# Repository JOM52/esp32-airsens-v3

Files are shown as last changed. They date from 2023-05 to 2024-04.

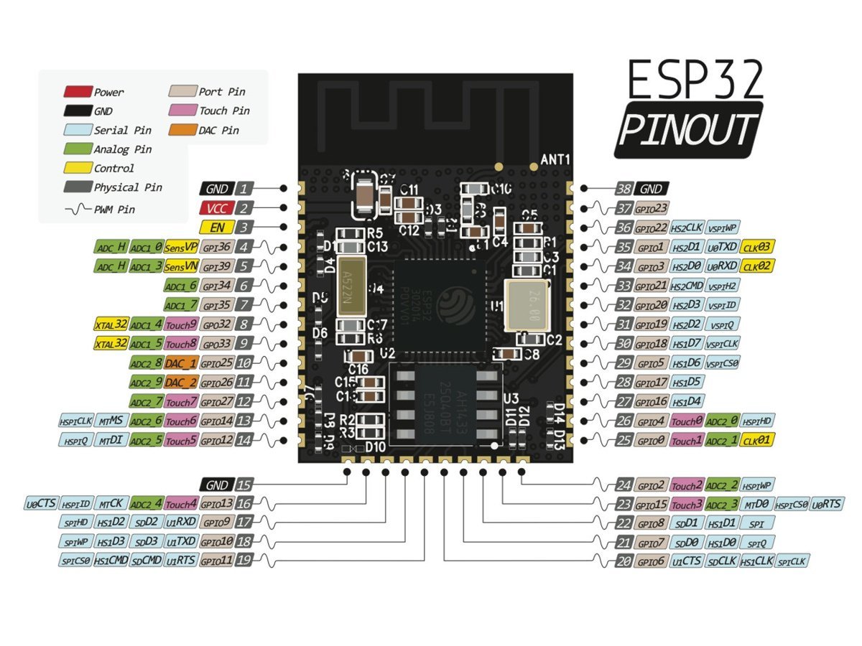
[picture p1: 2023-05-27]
doc/esp32-wroom-32_pinout.jpg

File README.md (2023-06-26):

# Projet : esp32-airsens 

Version 3

Dénomination des éléments:

- **Capteur (Sensor)**: composant qui permet la mesures d'une ou plusieurs grandeurs physiques;
- **Module de capteur ( Sensor module)**: microcontrôleur qui contrôle un ou plusieurs capteurs et se charge de transmettre les données vers une centrale;
- **Centrale (Host)**: microcontrôleur qui reçoit les données d'un ou plusieurs terminaux de mesure et qui les transmets vers un serveur domotique de type MQTT

**esp32-airsens** est un projet de domotique qui vise à créer des petits appareils intelligents et connectés pour contrôler l'environnement. Ils utilisent le processeur ESP32 et le langage Micropython. Ils peuvent détecter différents paramètres comme la température, l'humidité, la pression de l'air et le niveau de batterie. Ils transmettent ensuite ces données à une station centrale via un réseau sans fil. La station centrale est un système Liligo-TTGO qui reçoit les données des appareils, les publie sur un broker MQTT et les montre sur un écran. L'écran permet de visualiser les informations pertinentes pour chaque Module de capteur.

La version 3 du projet est basée sur la version 2 et introduit les éléments suivants:

- Association semi-automatique du Module de capteur et de la centrale.
- Lors de l'association du Module de capteur et de la centrale le terminal informe automatiquement la centrale du ou des capteurs connectés, des grandeurs mesurées ainsi que de l'ordre dans lequel ces informations seront transmises à la centrale par chaque terminal. 
- Identification du terminal par son adresse MAC
- Identification d'une mesure par l'adresse MAC du terminale de mesure ainsi que par le type de capteur utilisé.

## Schéma de principe
https://github.com/JOM52/esp32-airsens-v3/blob/main/schema/airsens_v3_0%20schema%20de%20principe.odg

## Module de capteur:

La version V1.0 proto du hardware fonctionne bien. Dans cette nouvelle version, le hardware est complétée avec un bouton et une led pour démarrer et contrôler le processus d'association du capteur avec la centrale. 

Pour réduire la consommation d'énergie, cette version hard ne contient que l'essentiel pour faire fonctionner le terminal. La configuration se fait, depuis le PC,  par une interface FTDI (USB to UART) qui se branche au besoin et, les batteries se rechargent à part.

https://github.com/JOM52/esp32-airsens-v3/blob/main/schema/airsens_v3_0.kicad_sch

### Hardware

Le hardware ESP32 est un microcontrôleur qui intègre des fonctionnalités de Wi-Fi et de Bluetooth, ainsi que des modules de gestion de l'alimentation, des filtres et des amplificateurs. Il peut se connecter à différents types de capteurs I2C, et transmets ces données vers la centrale par  le protocole de communication série synchrone ESP-now. 

##### firmware esp32/espnow

la version du firmware est trouvée sur le site: 
**[GitHub - glenn20/micropython-espnow-images: A collection of pre-compiled micropython images (including espnow support) for the esp32 and esp8266.](https://github.com/glenn20/micropython-espnow-images)** 
dans le répertoire:
**20220709_espnow-g20-v1.19.1-espnow-6-g44f65965b**
et le fichier est:
**firmware-esp32-GENERIC.bin**

Ce firmware convient pour les processeurs ESP32-WROOM-32 et Liligo TTGO t-display

**Attention:** la version v1.20.0 est sortie mais pose des problèmes au niveau de la communication espnow. De nombreux messages sont perdus. Donc on reste sur la version v1.19.1

##### Evolution airsens V3s:

- Ajout d'une cellule photovoltaïque pour la recharge en continu de la batterie du capteur.

### Software

Ce projet implémente les drivers pour les capteurs de type BME280, BME680 et HDC1080. Ces capteurs permettent de mesurer différentes grandeurs liées au climat ou à l'environnement. Depuis la version 2 du projet, on peut choisir le type et le nombre de capteurs à utiliser dans le fichier de configuration. Cette possibilité doit être utilisée à bon escient en tenant compte de l'impact sur la consommation dons sur l'autonomie de la batterie. Avec une batterie Li-Ion de 2Ah (type 18650), on peut, avec un seul capteur,  en prenant une mesure toutes les 5 minutes avoir un autonomie d'environ un an.

#### Fichier de configuration du capteur

Le fichier de configuration permet de personnaliser le fonctionnement d'un capteur sans avoir à modifier le code source. Il contient du code Micropython qui assigne des valeurs à des variables globales. Ces variables sont ensuite utilisées par le programme principal pour paramétrer les différents éléments du système. Le fichier de configuration n'a pas besoin d'une structure particulière, mais il peut être organisé en sections pour faciliter la lecture et la compréhension.

Le code ci-après permet de configurer un capteur connecté à un ESP32. Le capteur peut être de type hdc1080, bme280 ou bme680 et mesure la température, l'humidité, la pression, le gaz et l'altitude selon le cas. 

Le Module de capteur est alimenté par une batterie Li-Ion de 3.7V (3.2V - 4.2V) - type 6850. Pour économiser l'énergie consommée, le terminal est placé en ***deepsleep*** entre chaque mesure. Le temps de sommeil est défini dans le fichier de configuration. Lors d'un éveil, le processeur lit le fichier de configuration, initialise les constantes, charge les librairies nécessaire, initialise le capteur, fait la mesure, mesure l'état de la batterie, transmets les valeurs à la centrale puis se met en ***deepsleep***

La tension de la batterie est mesurée par un pont diviseur de tension. 

Le code utilise les constantes définies au début du fichier pour paramétrer les différents éléments du système. Par exemple, SENSOR_LOCATION indique le nom du capteur, T_DEEPSLEEP_MS indique la durée du mode deepsleep en millisecondes, SENSORS indique les types de capteurs disponibles et leurs mesures associées, ON_BATTERY indique si le capteur est alimenté par une batterie ou non, etc. 

L'association capteur-centrale .............................. à compléter ................................................

Le code ci-dessous montre un exemple de fichier de configuration pour ce système:

```
# acquisitions
SENSOR_LOCATION = 'domo_2' 
T_DEEPSLEEP_MS = 300000
# sensor
SENSORS = {
    'hdc1080':['temp', 'hum'],
    'bme280':['temp', 'hum', 'pres'],
    'bme680':['temp', 'hum', 'pres', 'gas', 'alt'],
  }
# power supply
TO_PRINT = True
ON_BATTERY = True
UBAT_100 = 4.2
UBAT_0 = 3.2
# I2C hardware config
BME_SDA_PIN = 21
BME_SCL_PIN = 22
# analog voltage measurement
R1 = 977000 # first divider bridge resistor
R2 = 312000 # second divider bridge resistor
DIV = R2 / (R1 + R2)  
ADC1_PIN = 35 # Measure of analog voltage (ex: battery voltage following)
#averaging of measurements
AVERAGING = 1
AVERAGING_BAT = 1
AVERAGING_BME = 1

# ESP-now
PROXY_MAC_ADRESS = '3C:61:05:0D:67:CC'
WIFI_CHANNEL = 1
```

### Messages

Les valeurs mesurées pour chaque grandeur sont regroupées et transmises au broker MQTT dans un seul message. Le format de principe du message est le suivant:

`msg = (topic, location, grandeur 1, grandeur 2, .... , grandeur n, bat, rssi)`

Les grandeurs mesurées sont dépendantes des possibilités du capteur par exemple:

- HDC1080 : température, humidité
- BME280  : température, humidité, pression
- BME680  : température, humidité, pression, qualité de l'air

Les valeurs transmises à MQTT sont fonction de la configuration définie dans le fichier _conf du capteur.

## Centrale

### Software

La centrale est le cœur du système de domotique. Elle a plusieurs fonctions :

- Elle reçoit et traite les messages valides envoyés par les capteurs sans fil.
- Elle adapte les messages au format de l'application de domotique choisie (domoticz, jeedom, ...).
- Elle transmet les valeurs de mesure à MQTT, un protocole de communication qui permet de diffuser les informations aux abonnés.
- Elle affiche différentes informations sur un écran couleur, comme les mesures et l'état des batteries des capteurs.

Les messages reçus ne sont pas confirmés au capteur. Cela signifie que si la centrale n'est pas disponible au moment où le capteur envoie un nouveau message, celui-ci est perdu. En principe cela ne pose pas de problème pour les mesures de grandeurs physiques qui varient peu dans le temps.

La centrale accepte tous les messages qui ont une structure correcte et qui proviennent d'un capteur dont elle connaît l'adresse MAC. Si le capteur est déjà enregistré dans le fichier de configuration et dans la mémoire programme, les nouvelles valeurs remplacent les anciennes. Sinon, le capteur est automatiquement reconnu et ajouté au fichier de configuration et à la mémoire programme.

La centrale dispose de deux boutons sur la version matérielle des Lilygo-ttgo qui permettent de sélectionner les différents affichages programmés. le choix se fait lorsque aucun bouton n'est pressé pendant 1 seconde.

Pour transmettre les mesures à MQTT, la centrale se connecte au réseau WIFI. Les valeurs de mesure sont formatées selon les besoins de l'application de domotique choisie puis envoyées au broker MQTT qui les publie aux abonnés.

### Fichier de configuration de la centrale

Le fichier de configuration est un fichier standard Micropython. 

```
#!/usr/bin/env python3
# -*- coding: utf-8 -*-
"""
file: airsens_central_conf.py 

author: jom52
email: jom52.dev@gmail.com
github: https://github.com/JOM52/esp32-airsens-class

v0.4.0 : 05.02.2023 --> first prototype
v0.4.1 : 05.03.2023 --> small changes Venezia
"""
from ubinascii import hexlify
from machine import unique_id
#SYSTEM
WAIT_TIME_ON_RESET = 10 # seconds to wait before the machine reset in case of error
# MQTT
BROKER_IP = '192.168.1.108'
TOPIC = 'airsens_v2'
BROKER_CLIENT_ID = hexlify(unique_id())

# TTGO
BUTTON_MODE_PIN = 35
BUTTON_PAGE_PIN = 0
DEFAULT_MODE = 0 # Mode auto
DEFAULT_ROW_ON_SCREEN = 5 # given by the display hardware and the font size
CHOICE_TIMER_MS = 1000 # milli seconds
BUTTON_DEBOUNCE_TIMER_MS = 10 # milli seconds
REFRESH_SCREEN_TIMER_MS = 20000 # mode auto: display next location each ... milli seconds

# WIFI
WIFI_WAN = 'jmb-airsens'
WIFI_PW = 'lu-mba01'

# BATTERY
BAT_MAX = 4.2 # 100%
BAT_MIN = 3.2 # 0%
BAT_OK = 3.4 # si ubat plus grand -> ok
BAT_LOW = 3.3 # si ubat plus petit -> alarm
BAT_PENTE = (100-0)/(BAT_MAX-BAT_MIN)
BAT_OFFSET = 100 - BAT_PENTE * BAT_MAX
# print('Charge bat % = ' + str(BAT_PENTE) + ' * Ubat' + ' + ' + str(BAT_OFFSET))

```

#### Code de la centrale évolution

*Dans une prochaine version il est prévu de modifier le programme pour:*

- *de crypter les message pour empêcher que les messages soient lus par des entités non autorisées.*

### Hardware

La centrale utilise un circuit Lilygo-ttgo qui comprend le processeur, une interface USB, un affichage de 135x240 pixels et deux boutons. Dans la version actuelle, ce circuit est utilisé tel quel. Les boutons sont utilisés comme suit:

- bouton 1 --> next **Mode**

- bouton 2 --> next **Page**

  le choix se fait lorsque aucun bouton n'est pressé pendant 1 seconde

### Connection réseau attribution des canaux

Il faut désactiver l'attribution automatique des canaux sur le routeur Wi-Fi : si le routeur Wi-Fi de votre réseau Wi-Fi est configuré pour attribuer automatiquement le canal Wi-Fi, il peut changer le canal du réseau s'il détecte des interférences provenant d'autres routeurs Wi-Fi. Lorsque cela se produit, les appareils ESP connectés au réseau Wi-Fi changeront également de canal pour correspondre au routeur, <u>mais les appareils ESPNow uniquement resteront sur le canal précédent et la communication sera perdue</u>. Pour corriger cela, configurez votre routeur Wi-Fi pour qu'il utilise un canal Wi-Fi fixe ou configurez vos appareils pour analyser à nouveau les canaux Wi-Fi s'ils ne parviennent pas à trouver leurs homologues attendus sur le canal actuel.

Il faut configurer le sensor pour utiliser le même canal (channel) que le router wifi. Le canal utilisé par la centrale peut être trouvée dans le menu ABOUT. C'est cette valeur qui doit être introduite dans le fichier de configuration du sensor p. ex.: WIFI_CHANNEL = 1

## Corrections à apporter

#### Capteurs

- [ ] Compléter le topic par le type de capteur et un id unique pour pouvoir assurer de différentier chaque capteur donc 
  le TOPIC sera constitué comme suit: SENSOR_LOCATION / SENSOR_TYPE / SENSOR_ID 
- [ ] Analyser si la possibilité d'avoir plusieurs sensors sur un seul capteur à du sens et si non supprimer le code correspondant
- [ ] Modifier la valeur du condensateur (C3) (tester 10uF) pour que le reset se fasse à l'enclenchement du sensor
- [ ] Etudier si l'implémentation du FTDI sur le capteur à du sens ou s'il rester avec un FTDI externe

#### Central

- [ ] Corriger : En cas de coupure réseau, le central se perd et ne redémarre pas automatiquement 
  - Le problème est le changement de canal par le router WIFI.  Voir: "Connection réseau attribution des canaux" ci-dessus

#### Communications Central-Capteurs

- [ ] Permettre à un capteur et un central de s'identifier mutuellement la première fois qu'ils se mettent en communication. P. ex.: un bouton "Synch" sur le capteur et sur le central qui lance la procédure et la synchro se fait.

#### Jeedom

- [ ] Actuellement c'est le RPI108 qui envoie un message au broker MQTT à destination de Jeedom. Corriger et envoyer le message directement depuis le ESP32 Central.

## GITHUB

Ce projet est maintenu dans GitHub, avec une licence GPL. Il est accessible par le lien 
https://github.com/JOM52/esp32-airsens-v2

Pravidondaz avril 2023

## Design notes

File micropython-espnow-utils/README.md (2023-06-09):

# Micropython ESPNow Utilities
A collection of small utilities for use with espnow and wifi on micropython

- `src/wifi.py`: A small module to bulletproof initialising wifi on ESP32 and
  ESP8266 devices.

These functions are designed to robustly and reliably account for differences
between esp8266 and esp32 devices and to ensure the wifi is always in a fully
known state (even after soft_reset).

```python
import wifi

sta, ap = wifi.reset()   # STA_IF on and disconnected, AP off, channel=1
sta, ap = wifi.reset(sta=True, ap=True, channel=6)
wifi.connect("ssid", "password")
wifi.status()            # Print details on wifi config
```

- `src/espnow_scan.py`: Scan channels to find an ESPNow peer.

```python
import espnow_scan

espnow_scan.scan(e, b'macadd')  # Print channel if found and leave set to channel

```

- `src/lazyespnow.py`: LazyESPNow() extends ESPNow class to catch and fix most
  common errors.

```python
from lazyespnow import LazyESPNow

peer = b'\xaa\xaa\xaa\xaa\xaa\xaa'
enow = LazyESPNow()
enow.send(peer, message)    # Automatically call active(True) and add_peer()
```

- `src/ntp.py`: Set the time from an NTP server over wifi.

```python
import ntp
ntp.server = "192.168.1.1"
ntp.settime()
```

- `src/timer.py`: A useful collection of easy to user python timer objects.

```python
import timer

for t in timer_ms(5000, 1000, raise_on_timeout=True):
    print(t)
```

- `src/echo.py`: A simple ESPNow server that echos messages back to the sender.

```python
import echo

echo.server()       # Wait for incoming messages and echo back to sender
```

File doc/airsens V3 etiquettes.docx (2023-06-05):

airsens V3 solar

AIRSENS
ID: solar_V3b
SN :20230002
Hard : V3-proto
Soft: V3

btn jaune: RESET
btn vert: PAIR
btn bleu: BOOT

Enter BOOT mode:
press and hold the BOOT button then press the
RESET button and then release both buttons.
Enter PAIR mode:
press and hold the PAIR button then press the
RESET button and then release both buttons.

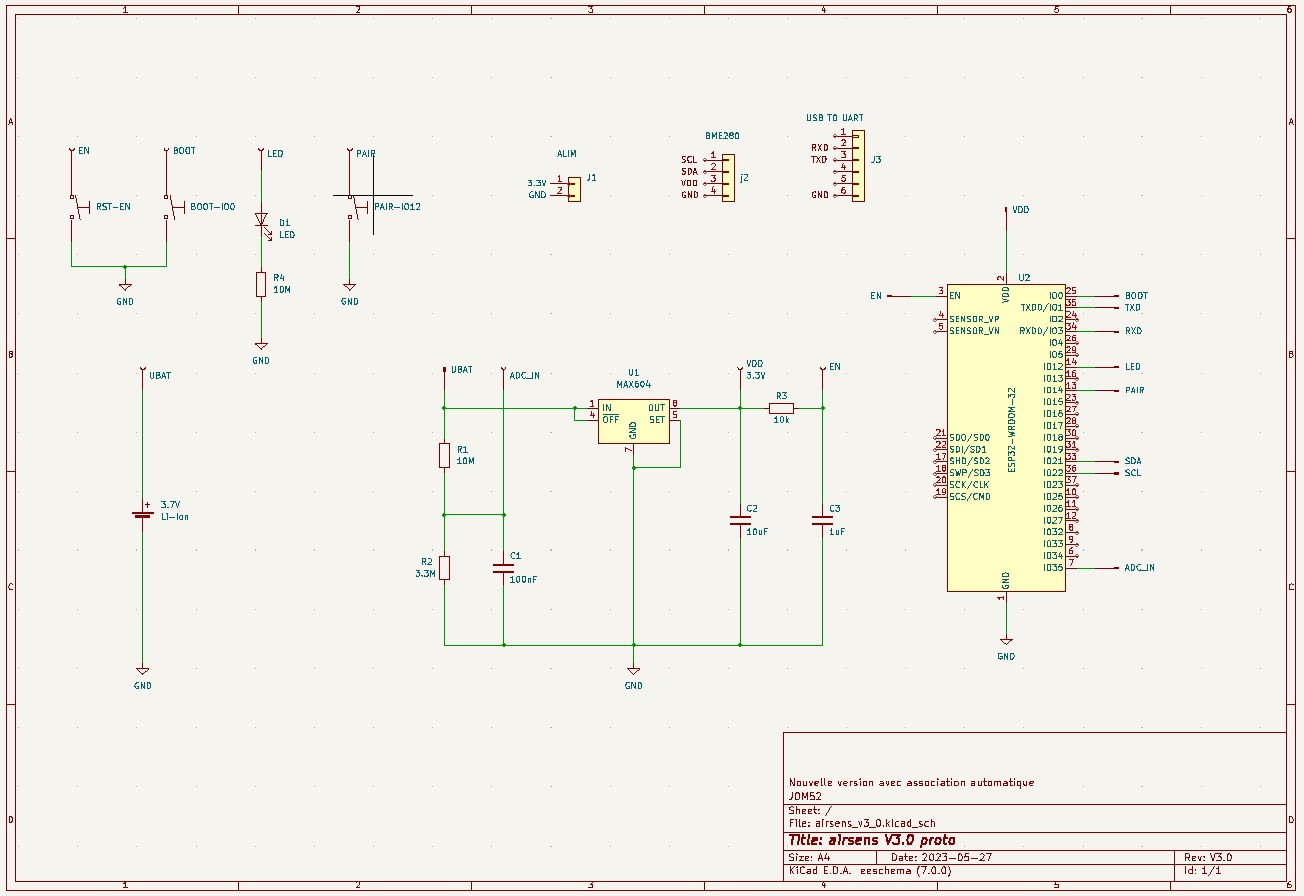
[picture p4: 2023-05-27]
schema/airsens_v3_0_schema.jpg

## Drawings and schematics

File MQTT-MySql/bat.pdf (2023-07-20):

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

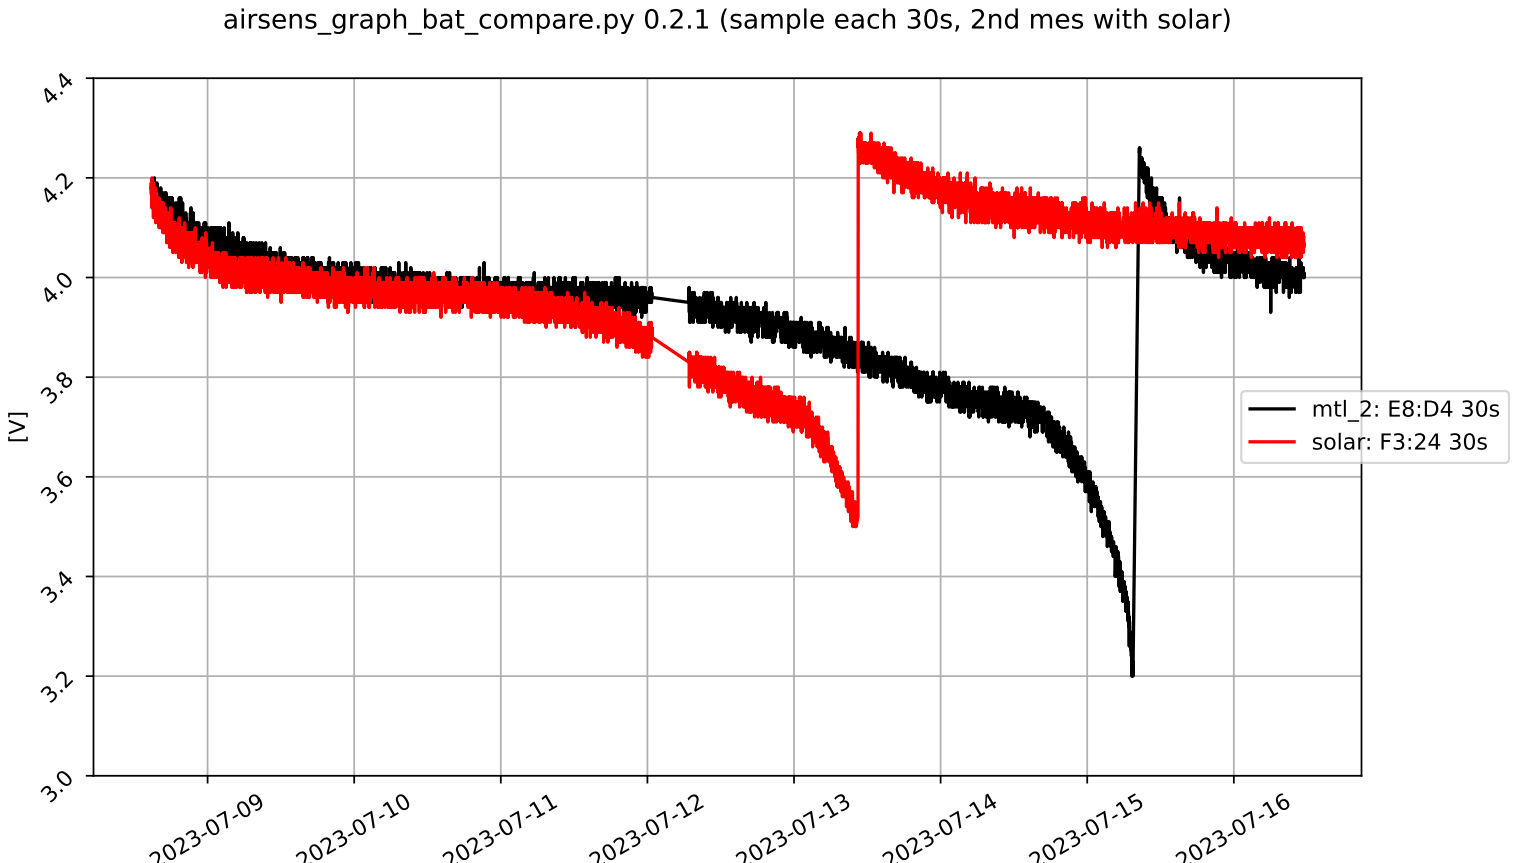
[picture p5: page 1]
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

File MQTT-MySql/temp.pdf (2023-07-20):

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

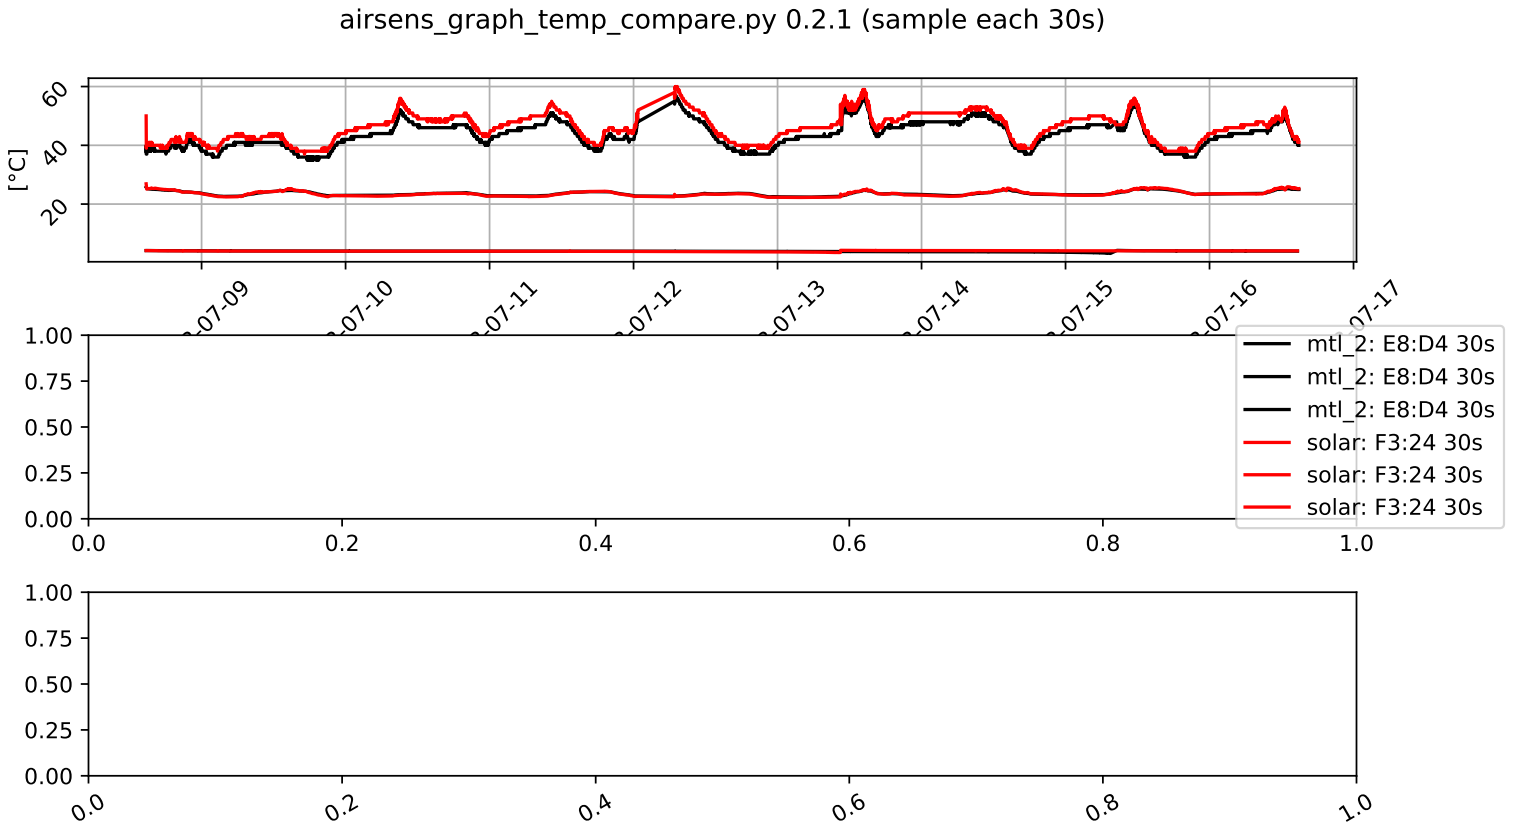
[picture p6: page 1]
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

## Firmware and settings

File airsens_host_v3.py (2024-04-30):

#!/usr/bin/env python3
# -*- coding: utf-8 -*-

"""
file: airsens_host.py 

author: jom52
email: jom52.dev@gmail.com
github: https://github.com/JOM52/esp32-airsens-v2

v0.4.0 : 05.02.2023 --> first prototype
v0.4.1 : 26.02.2023 --> optimisation du fichier conf
v0.4.2 : 27.02.2023 --> amelioration de la boucle Main
v0.4.3 : 28.02.2023 --> grand nettoyage
v0.4.4 : 01.03.2022 --> button_1_action simplified
v0.4.5 :05.03.2023 --> small changes Venezia
v1.0.0 : 11.03.2023 --> first production version
v1.1.0 : 07.04.2023 --> adaptation for domoticz process begin
-----------------------------------------------------------------------
v2.0.0 : 10.04.2023 --> new data structure no more compatible with old versions
v2.0.1 : 21.04.2023 --> small cosmetic changes
v2.0.2 : 21.04.2023 --> added menu ABOUT and modified WLAN MAC adresse format
v2.0.3 : 26.04.2023 --> small cosmetics changes
-----------------------------------------------------------------------
v3.0.0 : 30.05.2023 --> Begin with version3 of hard and soft. News are:
                        - Semi-automatic pairing between capteur and centrale
                        - During the pairing the sensor automatically informs the central of:
                                - the connected sensor(s),
                                - the measured quantities.
v3.0.1 : 10.06.2023 --> automatic pairing in developpement
v3.0.2 : 21.06.2023 --> renamed the program to airsens_host_v3.py
-----------------------------------------------------------------------
v3.1.0 : 23.06.2023 --> new datmessage structure no more compatible with old versions.
v3.1.1 : 30.06.2023 --> mqtt in service again (keepalive=60)
v3.1.2 : 14.11.2023 --> added reset, corrected display of mac and added uPython version on about menu
v3.1.3 : 09.01.2024 --> corrigé affichage de l'adresse capteur sur la page Overview
v3.1.4 : 22.03.2024 --> ajouté l'heure de la dernière acquis sur l'affichage 'AUTO'
v3.1.5 : 22.03.2024 --> désactivé le menu 'RESET'
v3.1.6 : 16.04.2024 --> ajouté la synchronistion RTC et dans le menu "about" la page "last measure"'
v3.1.7 : 19.04.2024 --> synchronise esp32 sur le net (ntptime)
v3.1.8 : 19.04.2024 --> optimized the page "Last measure"
"""
VERSION = '3.1.8'
PROGRAM_NAME = 'airsens_host_v3.py'
PROGRAM_NAME_SHORT = 'airsens'
print('Loading "' + PROGRAM_NAME + '" v' + VERSION + ' this may take a while ...')
import airsens_host_conf_v3 as conf

from ubinascii import hexlify, unhexlify
from machine import Pin, Timer, reset, RTC
from espnow import ESPNow
from utime import sleep_ms, time, gmtime, localtime
from network import WLAN, STA_IF, AP_IF, WIFI_PS_NONE
from ntptime import settime, time as ntptime
from math import ceil
from os import uname

from lib.log_and_count import LogAndCount
from lib.ttgo_display import TtgoTdisplay
from lib.simple import MQTTClient

class GlobalVar:
    data_pointer = None
    current_page = None
    current_mode = None
    mac_wlan = None
    mac_formated = None
    sta = None
    channel = None
    rssi = None
    last_mes = []
    last_mes_time = None
    last_mes_sensor = None


class Show:

    def __init__(self,
                 ttgo_display, # classes
                 datas, data_time  # lists to store the datas
                 ):
        self.ttgo_display = ttgo_display
        self.datas = datas
        self.data_time = data_time
        self.refresh_screen_timer = Timer(0)  # timer to switch to the next ecran
        self.refresh_screen_timer.init(period=conf.REFRESH_SCREEN_TIMER_MS, mode=Timer.PERIODIC,
                                       callback=self.refresh_screen_from_timer)
    
    def get_formated_time(self, time=None, ret_type=None):
        if time is None:
            dt = localtime()
        else:
            dt = time
#         year = int(str(dt[0])[2:])
        year = '{:02d}'.format(int(str(dt[0])[2:]))
        month = '{:02d}'.format(dt[1])
        day = '{:02d}'.format(dt[2])
        hour = '{:02d}'.format(dt[3])
        minute = '{:02d}'.format(dt[4])
        second = '{:02d}'.format(dt[5])
        
        if ret_type == None:
            return day + '.' + month + '.' + year + ' ' + hour + ':' + minute + ':' + second
        elif ret_type == 'd':
            return day + '.' + month + '.' + year 
        elif ret_type == 't':
            return hour + ':' + minute + ':' + second
        else:
            return '-.-.- -:-:-'

    # called by the timer because he give a not usefull param
    # and the procedure refresh_screen don't use it
    def refresh_screen_from_timer(self, z):
        self.refresh_screen()

    # refresh the screen for any mode
    def refresh_screen(self):
            
        self.ttgo_display.cls()
        if GlobalVar.current_mode == 0: # mode auto
            GlobalVar.data_pointer = self.manage_data_pointer(GlobalVar.data_pointer, len(self.datas))
            self.display_auto(self.datas, GlobalVar.data_pointer)
            
        elif GlobalVar.current_mode == 1: # mode overview
            self.display_overview(title='OVERVIEW ', n_row=4, n_col=1, data_list=self.datas,
                                       current_page=GlobalVar.current_page, current_mode=GlobalVar.current_mode)
        elif GlobalVar.current_mode == 2: # mode battery status
            self.display_overview(title='BATTERY ', n_row=4, n_col=1, data_list=self.datas,
                                       current_page=GlobalVar.current_page, current_mode=GlobalVar.current_mode)
        elif GlobalVar.current_mode == 3: # mode About
            if GlobalVar.current_page == 0:
                self.ttgo_display.write_line(0, PROGRAM_NAME_SHORT + ' v' + VERSION + '  p1/4', color=self.ttgo_display.COLOR_WHITE)  
                self.ttgo_display.write_about_line(1,'MAC:', str(hexlify(GlobalVar.mac_wlan, ':').decode().upper()))
                self.ttgo_display.write_about_line(2,'WIFI channel:', str(GlobalVar.sta.config("channel")))
                self.ttgo_display.write_about_line(3,'WAN:', conf.WIFI_SSID)
                self.ttgo_display.write_about_line(4,'host IP:', str(GlobalVar.sta.ifconfig()[0]))
            elif GlobalVar.current_page == 1:
                self.ttgo_display.write_line(0, PROGRAM_NAME_SHORT + ' v' + VERSION + '  p2/4', color=self.ttgo_display.COLOR_WHITE)  
                self.ttgo_display.write_about_line(1,'MQTT topic:', '')
                self.ttgo_display.write_about_line(2,'   ', conf.BROKER_TOPIC)
                self.ttgo_display.write_about_line(3,'MQTT broker IP:', '')
                self.ttgo_display.write_about_line(4,'   ', conf.BROKER_IP)
            elif GlobalVar.current_page == 2:
                v_name = uname()[1]
                v = uname()[3]
                v_all = v.split(' ')
                v_detail = v_all[0].split('-')
                v_version = v_detail[0]
                v_plus = v_detail[1] + '-' + v_detail[2] + '-' + v_detail[3]
                v_date = v_all[2]
                self.ttgo_display.write_line(0, PROGRAM_NAME_SHORT + ' v' + VERSION + '  p3/4', color=self.ttgo_display.COLOR_WHITE)  
                self.ttgo_display.write_about_line(1, 'uPython version:', '')
                self.ttgo_display.write_about_line(2, '', v_name + ' ' + v_version)
                self.ttgo_display.write_about_line(3, '', v_plus)
                self.ttgo_display.write_about_line(4, '', v_date)
            elif GlobalVar.current_page == 3:
                self.ttgo_display.write_line(0, PROGRAM_NAME_SHORT + ' v' + VERSION + '  p4/4', color=self.ttgo_display.COLOR_WHITE)  
                self.ttgo_display.write_line(1,'Last measure', '', '', color=self.ttgo_display.COLOR_ORANGE)
                if GlobalVar.last_mes:
                    row_index = 2
                    i_max = len(GlobalVar.last_mes) # - 1
                    i_min = 0 if i_max < 3 else i_max - 3
                    for i in range(i_max, i_min, -1):
                        list_index = i - 1
                        self.ttgo_display.write_line_lastmes(row_index, GlobalVar.last_mes[list_index][0][:5],
                                                              self.get_formated_time(GlobalVar.last_mes[list_index][1], 'd'),
                                                              self.get_formated_time(GlobalVar.last_mes[list_index][1], 't'),
                                                              txt_color=self.ttgo_display.COLOR_CYAN,
                                                              val_color=self.ttgo_display.COLOR_YELLOW)
                        row_index += 1
                        
                else:
                    self.ttgo_display.write_line(2, 'No datas', color=self.ttgo_display.COLOR_RED)
#         elif GlobalVar.current_mode == 4: # mode Reset
#             reset()


    # display the data for the modes auto
    def display_auto(self, datas, data_pointer):
        if datas:
            location, temp_f, hum_f, pres_f, bat_val, bat_f, bat_pc_f, bat_color = datas[data_pointer]
            self.ttgo_display.write_line(0, location[-8:], color=self.ttgo_display.COLOR_WHITE)
            self.ttgo_display.write_line(1, 'Temp = ' + str(temp_f) + '"C', color=self.ttgo_display.COLOR_CYAN)
            self.ttgo_display.write_line(2, 'Hum  = ' + str(hum_f) + '%', color=self.ttgo_display.COLOR_CYAN)
            if float(pres_f) > 0:
                self.ttgo_display.write_line(3, 'Pres = ' + str(pres_f) + 'hPa', color=self.ttgo_display.COLOR_CYAN)
            self.ttgo_display.write_line(4, 'Batt = ' + str(bat_f) + 'V ' + str(bat_pc_f) + '%', color=bat_color)
        else:
            self.ttgo_display.write_line(1, 'No datas', color=self.ttgo_display.COLOR_RED)
            

    def display_overview(self, title, n_row, n_col, data_list, current_page, current_mode):
        self.ttgo_display.cls()
        if data_list:
            len_data_list = len(data_list)
            self.ttgo_display.write_line(0, title + ' p '
                                         + str(current_page+1) + '/'
                                         + '{:.0f}'.format(ceil(len_data_list/n_row)),
                                         color=self.ttgo_display.COLOR_WHITE)
            for i in range(0, len(data_list)):
                if (current_page * n_row) <= i < ((current_page + 1) * n_row):
                    row = i - current_page * n_row + 1
                    location, temp_f, hum_f, pres_f, bat_val, bat_f, bat_pc_f, bat_color = data_list[i]
                    if current_mode == 1:
                        self.ttgo_display.write_line_overview(row, '...' + location[-8:], str(temp_f) + 'C', str(hum_f) + '%',
                                                              txt_color=self.ttgo_display.COLOR_CYAN,
                                                              val_color=self.ttgo_display.COLOR_YELLOW)
                    elif current_mode == 2:
                        self.ttgo_display.write_line_bat(row, '...' + location[-8:], str(bat_f) + 'V', str(bat_pc_f) + '%',
                                                         txt_color=self.ttgo_display.COLOR_CYAN, bat_color=bat_color)
        else:
            self.ttgo_display.write_line(1, 'No datas', color=self.ttgo_display.COLOR_RED)
            
    def manage_data_pointer(self, pointer, len_data_list):
        if pointer < len_data_list - 1:
            pointer += 1
        else:
            pointer = 0
        return pointer


class Menu:

    def __init__(self,
                 show, ttgo_display, # classes
                 datas, data_time  # lists to store the datas
                 ):
        self.interrupt_pin = None
        self.show = show
        self.ttgo_display = ttgo_display
        self.choice_ok_timer = Timer(1)  # timer to valid the mode choice
        self.button_debounce_timer = Timer(2)  # timer to debounce the switches
        self.datas = datas
        self.data_time = data_time

    # callback procedure for any button pressed
    # execute the action corresponding to the pressed button
    def on_button_pressed(self, z):
        if self.interrupt_pin == Pin(conf.BUTTON_MODE_PIN):
            self.button_1_action()
        elif self.interrupt_pin == Pin(conf.BUTTON_PAGE_PIN):
            self.button_2_action()

    # debounce any button pressed 
    def button_debounce(self, pin):
        self.interrupt_pin = pin
        self.button_debounce_timer.init(mode=Timer.ONE_SHOT,
                                        period=conf.BUTTON_DEBOUNCE_TIMER_MS, callback=self.on_button_pressed)

    # execute actions selected by the button 1 (executed from the timer choice_ok_timer)
    def choice_ok(self, z):
        # after any change in the modes reinit the refresh timer
        self.show.refresh_screen_timer.deinit()
        if GlobalVar.current_mode == 0:
            'mode auto'
            GlobalVar.data_pointer = -1
        elif GlobalVar.current_mode == 1 or GlobalVar.current_mode == 2:
            'mode overview'
            GlobalVar.current_page = 0
        elif GlobalVar.current_mode == 3:
            GlobalVar.current_page = 0
            pass
           
        self.show.refresh_screen_timer.init(period=conf.REFRESH_SCREEN_TIMER_MS, mode=Timer.PERIODIC,
                                       callback=self.show.refresh_screen_from_timer)
        self.show.refresh_screen()

    def button_1_action(self):
        MODES = ['AUTO', 'OVERVIEW', 'BATTERY', 'ABOUT']# , 'RESET'] # modes
        self.choice_ok_timer.deinit()
        self.ttgo_display.cls()
        # increment ttgo_curent_mode and reset if too big
        len_modes = len(MODES) # store the length of the list
        GlobalVar.current_mode = (GlobalVar.current_mode + 1) % len_modes # use modulo to wrap around
        # display the menu with the active line in yellow
        # use a list comprehension to create a list of colors based on the current mode
        colors = [self.ttgo_display.COLOR_YELLOW if i == GlobalVar.current_mode else self.ttgo_display.COLOR_CYAN for i in range(len_modes)]
        # loop over the modes and colors and write each line
        for i, (mode, color) in enumerate(zip(MODES, colors)):
            self.ttgo_display.write_line(i, mode, color=color)
        # init timer to do action of the select menu entry
        self.choice_ok_timer.init(mode=Timer.ONE_SHOT, period=conf.CHOICE_TIMER_MS, callback=self.choice_ok)
        # change the current mode

    # change the current page
    def button_2_action(self):
        self.show.refresh_screen_timer.deinit()
        if GlobalVar.current_mode == 0:
            # mode auto
            pass
        elif GlobalVar.current_mode == 1 or GlobalVar.current_mode == 2:
            # mode overview
            current_page_inc = 1
            len_liste = 4
            GlobalVar.current_page = self.get_next_page(self.datas, len_liste, GlobalVar.current_page, current_page_inc)
        elif GlobalVar.current_mode == 3:
            # mode About
            GlobalVar.current_page = (GlobalVar.current_page + 1) % 4
            pass
           
        self.show.refresh_screen_timer.init(period=conf.REFRESH_SCREEN_TIMER_MS, mode=Timer.PERIODIC,
                                       callback=self.show.refresh_screen_from_timer)
        self.show.refresh_screen()

    def get_next_page(self, datas, len_liste, current_page, current_page_inc):
        
        # Calculer le nombre total de pages à afficher
        n_pages = len(datas) // len_liste
        if len(datas) % len_liste > 0:
            n_pages += 1
        # Augmenter ou diminuer la page courante selon l'incrément
        # Si la page courante dépasse le nombre total de pages, revenir à la première page
        current_page = (current_page + current_page_inc) % n_pages
        return current_page
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

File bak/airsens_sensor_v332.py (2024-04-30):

#!/usr/bin/env python3
# -*- coding: utf-8 -*-

"""
file: airsens_sensor_multi.py 

author: jom52
email: jom52.dev@gmail.com
github: https://github.com/JOM52/esp32-airsens-now

The sensors are made with an ESP32 microcontroller and can be powered by battery or by USB.
They transmit the data to a host also realized with an ESP32 by a ESPnow interface

v0.1.0 : 17.08.2022 --> first prototype based on airsens_ble_sensor.py
----------------------------------------------------------------------
v0.2.0 : 07.09.2022 --> modified for new log_and_count.py version ---> no more compatible with previous versions
v0.2.1 : 07.09.2022 --> espnow and wifi powered off before going to deepsleep
v0.2.2 : 19.12.2022 --> small cosmetices changes
v0.2.3 : 20.12.2022 --> temporary change for develop proxy display
v0.2.4 : 03.01.2022 --> added fake sensor for test
v0.2.5 : 11.01.2023 --> name of the conf file modified to airsens_now_sensor_display_conf.py
v0.3.0 : 17.02.2023 --> new version for long time test (tld)
v0.3.1 : 26.02.2023 --> usage of conf values simplidied
----------------------------------------------------------------------
v1.0.0 : 12.03.2023 --> First production version - one version for bme280 and hdc1080
----------------------------------------------------------------------
v2.0.0 : 02.04.2023 --> New data concept
v2.0.1 : 21.04.2023 --> Small cosmetic changes
v2.0.2 : 22.04.2023 --> improved espnow message sending by fixing the wifi channel
v2.0.3 : 26.04.2023 --> Added TO_PRINT in conf file 
----------------------------------------------------------------------
v3.0.0 : 30.05.2023 --> Begin with version3 of hard and soft. News are:
                        - Semi-automatic pairing between capteur and host
                        - During the pairing the sensor automatically informs the host of:
                                - the connected sensor(s),
                                - the measured quantities.
v3.0.1 : 30.05.2023 --> implémentation logiciel de la led et du bouton pour le pairage (éléments de base)
v3.0.2 : 06.06.2023 --> implémentation lecture tension cellule photovoltaique
v3.0.3 : 18.06.2023 --> MTL essai sur wifi mtl
----------------------------------------------------------------------
v3.1.0 : 23.06.2023 --> new datmessage structure no more compatible with old versions.
v3.1.1 : 23.06.2023 --> correction on count of messages lost
v3.1.2 : 25.06.2023 --> standardised the integration of bat and sol in message
v3.1.3 : 25.06.2023 --> final print improved
v3.2.4 : 30.06.2023 --> battery and solar pannel voltage transmitted only ones (that of the last sensor)
v3.3.0 : 08.07.2023 --> stable version for long time test
v3.3.1 : 23.11.2023 --> added reset if error in main loop
v3.3.2 : 26.11.2023 --> improve main error handling 
"""

from utime import ticks_ms, sleep_ms
start_time = ticks_ms()

# PARAMETERS ========================================
PRG_NAME = 'airsens_sensor_v3_scan'
PRG_VERSION = '3.3.2'
CONF_FILE_NAME = 'airsens_sensor_conf_v3.py'
import airsens_sensor_conf_v3 as conf  # configuration file
# IMPORTATIONS ======================================
from ubinascii import hexlify, unhexlify
from machine import Pin, freq, TouchPad, reset, reset_cause
from machine import ADC, SoftI2C, deepsleep, Timer, DEEPSLEEP_RESET, EXT0_WAKE, HARD_RESET
from machine import unique_id
from sys import exit
from network import WLAN, STA_IF, AP_IF
from espnow import  ESPNow
from lib.log_sensor import LogSensors
log = LogSensors()

# SENSORS ============================================
# if 'bme280' in conf.SENSORS:
#     import lib.bme280 as bme280
if 'bme280' in conf.SENSORS:
    import lib.bme280_float as bme280
if 'bme680' in conf.SENSORS:
    import lib.bme680 as bme680
if 'hdc1080' in conf.SENSORS:
    import lib.hdc1080 as hdc1080
# ADC MEASUREMENTS ===================================
if conf.ON_BATTERY:
    bat_adc_in = ADC(Pin(conf.ADC1_PIN))            
    bat_adc_in.atten(ADC.ATTN_6DB ) # Umax = 2V
    bat_adc_in.width(ADC.WIDTH_12BIT) # 0 ... 4095
if conf.SOLAR_PANEL:
    sol_adc_in = ADC(Pin(conf.SOL_PIN))            
    sol_adc_in.atten(ADC.ATTN_6DB ) # Umax = 2V
    sol_adc_in.width(ADC.WIDTH_12BIT) # 0 ... 4095
# LED AND BUTTONS =====================================
LED = Pin(conf.LED_PIN, Pin.OUT)
BTN_PAIR = Pin(conf.BUTTON_PAIR_PIN, mode = Pin.IN, pull=Pin.PULL_UP)
PAIR_STATUS = not BTN_PAIR.value()
# I2C ==================================================
i2c = SoftI2C(scl=Pin(conf.BME_SCL_PIN), sda=Pin(conf.BME_SDA_PIN), freq=10000)
# FUNCTIONS ===========================================
# led flash
def blink_led(freq='high', n_repeat=3):
    if freq =='high': t_ms = 100
    elif freq == 'med': t_ms = 250
    elif freq == 'low': t_ms = 500
    elif freq == 'very_low': t_ms = 1000
    if n_repeat != 0:
        for n in range(n_repeat):
            LED.on()
            sleep_ms(t_ms)
            LED.off()
            sleep_ms(t_ms)
    else:
        while True:
            LED.on()
            sleep_ms(t_ms)
            LED.off()
            sleep_ms(t_ms)
        
# print and store infos after the end of the measure
def end_print(total_time, t_deepsleep):
    msg_send = log.counters('passe', True)
    msg_lost = log.counters('lost', False)
    msg_good = msg_send - msg_lost
    if conf.TO_PRINT:
        print('msg send:' + str(msg_send) + ' good:' + str(msg_good) + ' lost:' + str(msg_lost) +
              ' - error:' + str(log.counters('error', False)), '-->' , str(total_time) + 'ms')
        print('going to deepsleep for: ' + str(t_deepsleep) + ' ms')
        print('=================================================')
    else:
        print(str(total_time) + 'ms')
    deepsleep(t_deepsleep)
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

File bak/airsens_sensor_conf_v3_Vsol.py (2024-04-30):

# ESP-now
HOST_MAC_ADRESS="3C:61:05:0D:67:CC"
WIFI_CHANNEL = 11
# acquisitions
SENSOR_LOCATION = 'mtl_1' 
T_DEEPSLEEP_MS = 30000
# sensor
SENSORS = {'bme280':['temp', 'hum', 'pres', 'bat'], }
# power supply
TO_PRINT = True
ON_BATTERY = True
UBAT_100 = 4.2
UBAT_0 = 3.2
# I2C hardware config
BME_SDA_PIN = 21
BME_SCL_PIN = 22
# analog voltage measurement
R1 = 977000 # first divider bridge resistor
R2 = 312000 # second divider bridge resistor
DIV = R2 / (R1 + R2)  
ADC1_PIN = 35 # Measure of analog voltage (ex: battery voltage following)
SOL_PIN = 34 # measure of the solar panel voltage
#averaging of measurements
AVERAGING = 1
AVERAGING_BME = 1
# PAIR
LED_PIN = 12
BUTTON_PAIR_PIN = 14 # no du port gpio
# SOLAR
# SOLAR = False

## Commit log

2023-05-28 Ready for the hardware
    [airsens_v3_0.kicad_sch, airsens_v3_0_impantation.xlsx]
2023-06-04 Version v3 solar
    [airsens_solaire_s3_0.kicad_sch, airsens_v3_0_impantation.xlsx]
2023-06-26 airsens sensor v3.1.3
